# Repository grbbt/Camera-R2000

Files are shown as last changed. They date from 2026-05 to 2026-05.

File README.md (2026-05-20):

# R2000

> A compact, round-bodied digital camera built around the ESP32-P4, designed for fun, accessible photography with a deliberate film-inspired aesthetic.





---

## Overview

The R2000 is a hand-held digital camera on an 70mm circular PCB. Fixed-focus wide-angle lens, film-style filters, RGB flash, and a round touchscreen — all driven by an ESP32-P4 + ESP32-C6 SOM. It's a camera that prioritises feel and fun over clinical image quality.

---

## Features

- **80mm round PCB** — compact, pocketable form factor
- **OV5640 MIPI CSI-2 sensor** — 5MP, fixed focus, wide angle (~1.5m hyperfocal)
- **2.1" round ST7701S touchscreen** — live viewfinder and menu UI via LVGL
- **3-channel RGB flash** — independent R/G/B control for software-adjustable colour temperature
- **Film aesthetic filters** — colour grading, grain, vignette, and light leak applied in-camera
- **microSD card storage** — JPEG capture written directly from hardware encoder
- **USB-C** — charging and file transfer
- **1000mAh LiPo** — onboard single-cell battery

---

## Electrical Hardware

### Core SOM

**Guition JC-ESP32P4-M3-C6** — a dual-chip SOM combining:
- **ESP32-P4** — main application processor, MIPI CSI camera input, RGB display output, hardware JPEG encode, SD/MMC
- **ESP32-C6** — WiFi 6 / BLE 5 radio for wireless transfer and future remote control

### Schematic

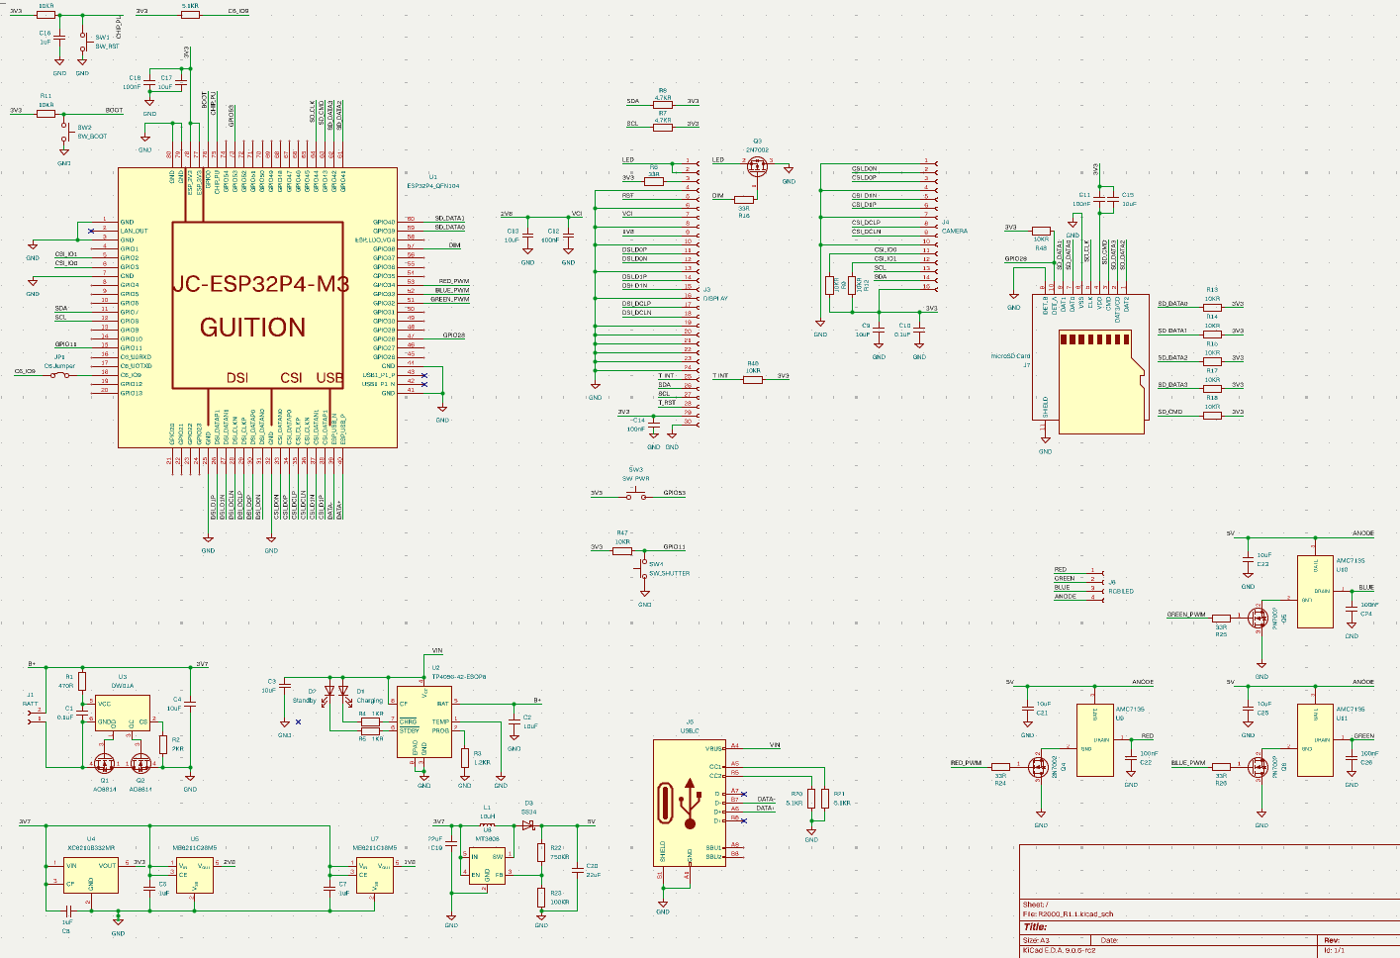
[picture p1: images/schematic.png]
Schematic


### PCB

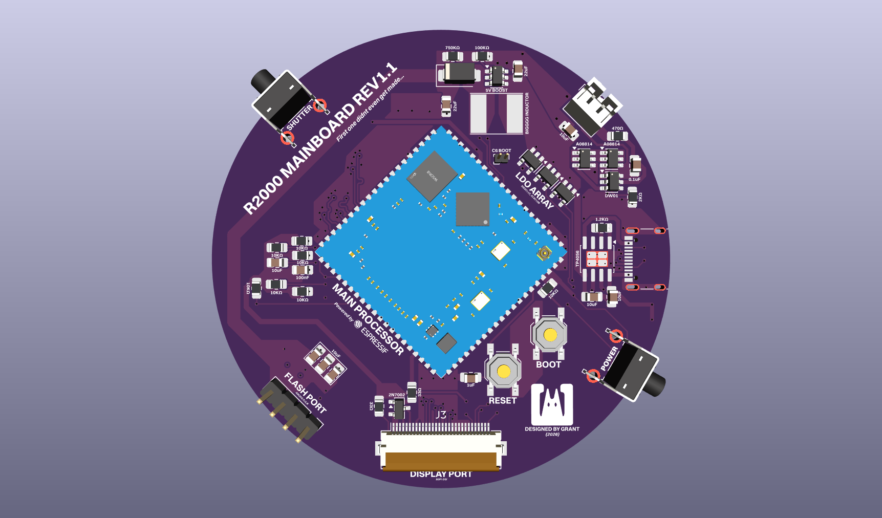
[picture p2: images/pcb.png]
PCB


| Parameter | Value |
|---|---|
| Diameter | 70mm |
| Layers | 4 |
| Design tool | KiCad |

- LDO bank placed adjacent to OV5640 to keep power traces short
- MT3608 boost converter isolated from camera rails to reduce switching noise
- RGB panel interface traces serpentined for length matching
- SD card traces kept short with 10kΩ pull-ups on CMD and DAT lines

### Camera

| Parameter | Value |
|---|---|
| Sensor | OV5640 |
| Interface | MIPI CSI-2 (2-lane) |
| Resolution | 5MP (2592×1944) |
| Focus | Fixed, wide angle |
| Hyperfocal | ~1.5m (everything from ~80cm to ∞ sharp) |
| Autofocus | None — VCM unused |

### Display

| Parameter | Value |
|---|---|
| Driver IC | ST7701S |
| Size | 2.1" round |
| Diameter | ~54mm |
| Interface | RGB parallel |
| Touch IC | GT911 (I2C) |

### Flash

Three independent channels let you tune the colour temperature of each shot in software — or go full auto white-balance assist by sampling the scene before firing.

| Channel | Driver | Supply |
|---|---|---|
| Red 1W LED | AMC7135 (350mA CC) | 5V (MT3608 boost) |
| Green 1W LED | AMC7135 (350mA CC) | 5V (MT3608 boost) |
| Blue 1W LED | AMC7135 (350mA CC) | 5V (MT3608 boost) |

### Power

| Rail | Regulator | Supplies |
|---|---|---|
| 3.3V | XC6210B332 (1A) | SOM, display logic, SD, GT911 |
| 2.8V | ME6211C28 (600mA) | OV5640 AVDD |
| 1.8V | ME6211C18 (600mA) | OV5640 DOVDD |
| 1.5V | ME6211C15 (600mA) | OV5640 DVDD |
| 5V (flash) | MT3608 boost | RGB flash rail |

Battery: 1000mAh single-cell LiPo, ~503040 form factor, charged via TP5100.

---

## Firmware

### Stack

| Layer | Component |
|---|---|
| RTOS | FreeRTOS (via ESP-IDF v5.3+) |
| Camera | `esp_cam_sensor` + `esp_video` (MIPI CSI DMA) |
| JPEG encode | `esp_jpeg` — hardware-accelerated on ESP32-P4 |
| Display | `esp_lcd` (ST7701S) + `esp_lcd_touch` (GT911) |
| UI | LVGL — hardware-accelerated via P4 PPA |
| Storage | `esp_vfs_fat` + `sdmmc` |

### Task Architecture

```
Core 0                         Core 1
├── Camera capture task        ├── LVGL UI task
├── JPEG encode task           └── Touch polling task
└── SD write task
```

Both cores run in genuine parallel — the live viewfinder never stutters during a write.

### Capture Pipeline

```
OV5640 sensor
  └── MIPI CSI-2 DMA → PSRAM framebuffer
        └── HW JPEG encoder
              └── SD write (FAT32)
                    └── JPEG file
```

### Filters

- **Colour grading** — warm/cool/cross-process presets
- **Grain simulation** — luminance-dependent noise overlay
- **Vignette** — radial falloff, adjustable intensity
- **Light leak** — randomised edge flare, optional per-shot

---

## Getting Started

### Prerequisites

- ESP-IDF v5.3 or later ([installation guide](https://docs.espressif.com/projects/esp-idf/en/latest/esp32p4/get-started/))
- KiCad 8.x for hardware files

### Build Firmware

```bash
git clone https://github.com/yourusername/R2000.git
cd R2000/firmware

idf.py set-target esp32p4
idf.py menuconfig     # Set SD card GPIO, display config, etc.
idf.py build
idf.py -p /dev/ttyUSBx flash monitor
```

### Hardware Assembly

1. Order PCB from JLCPCB using files in `hardware/pcb/`
2. Source components from `hardware/bom/` — LCSC preferred for basic parts
3. Flash firmware before installing display and camera to simplify debug access

---

## GPIO Map

See [`docs/gpio_map.md`](docs/gpio_map.md) for the full 30-pin assignment covering RGB display, GT911 touch, OV5640 MIPI/I2C/XCLK, SD card, flash channels, and shutter button.

---

## Design Philosophy

The R2000 isn't trying to be a precise instrument. No AF hunting, no deep menus, no lab-grade colour science. Wide angle and fixed focus means everything is sharp the moment you raise it. The filters are baked in, not bolted on. Round is unusual and that's the point.

If you want clinical accuracy, this is the wrong camera. If you want something that makes you actually want to take pictures, that's what this is for.

---

## Status

| Electrical | Status |
|---|---|
| PCB layout | ✅ First pass complete |
| Power system | ✅ LDO selection finalised |
| PCB Assembly & Testing | 🔧 In progress |

| Software | Status |
|---|---|
| Display / LVGL | 🔧 In progress |
| WiFi upload (C6) | 🔧 In progress |
| RGB flash driver | ⬜ Not started |
| Film filters | ⬜ Not started |
| SD storage | ⬜ Not started |

| Hardware | Status |
|---|---|
| Case Initial Design | 🔧 In progress |
| Case Prototyping | 🔧 In progress |

---

## License

Hardware and firmware released under [MIT License](LICENSE).

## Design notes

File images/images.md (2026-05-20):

# Development images
---
Schematic
PCB

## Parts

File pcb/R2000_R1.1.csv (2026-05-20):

Reference | Qty | Value | DNP | Exclude from BOM | Exclude from Board | Footprint | Datasheet
C1,C10 | 2 | 0.1uF |  |  |  | Capacitor_SMD:C_0805_2012Metric_Pad1.18x1.45mm_HandSolder | ~
C2,C3,C4,C9,C13,C15,C17,C21,C23,C25 | 10 | 10uF |  |  |  | Capacitor_SMD:C_0805_2012Metric_Pad1.18x1.45mm_HandSolder | ~
C5,C7,C8,C16 | 4 | 1uF |  |  |  | Capacitor_SMD:C_0805_2012Metric_Pad1.18x1.45mm_HandSolder | ~
C11,C12,C14,C18,C22,C24,C26 | 7 | 100nF |  |  |  | Capacitor_SMD:C_0805_2012Metric_Pad1.18x1.45mm_HandSolder | ~
C19,C20 | 2 | 22uF |  |  |  | Capacitor_SMD:C_0805_2012Metric_Pad1.18x1.45mm_HandSolder | ~
D1 | 1 | Charging |  |  |  | LED_SMD:LED_1206_3216Metric_Pad1.42x1.75mm_HandSolder | ~
D2 | 1 | Standby |  |  |  | LED_SMD:LED_1206_3216Metric_Pad1.42x1.75mm_HandSolder | ~
D3 | 1 | SS34 |  |  |  | Diode_SMD:D_SMA | https://www.vishay.com/docs/88751/ss32.pdf
J1 | 1 | BATT |  |  |  | Connector_JST:JST_PH_B2B-PH-K_1x02_P2.00mm_Vertical | ~
J3 | 1 | DISPLAY |  |  |  | Connector_FFC-FPC:Hirose_FH12-30S-0.5SH_1x30-1MP_P0.50mm_Horizontal | ~
J4 | 1 | CAMERA |  |  |  | Connector_FFC-FPC:TE_1-84952-5_1x15-1MP_P1.0mm_Horizontal | ~
J5 | 1 | USB_C |  |  |  | Connector_USB:USB_C_Receptacle_G-Switch_GT-USB-7010ASV | https://www.usb.org/sites/default/files/documents/usb_type-c.zip
J6 | 1 | RGB LED |  |  |  | Connector_PinHeader_2.54mm:PinHeader_1x04_P2.54mm_Vertical | ~
J7 | 1 | microSD Card |  |  |  | Connector_Card:microSD_HC_Hirose_DM3AT-SF-PEJM5 | https://www.hirose.com/en/product/document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
JP1 | 1 | C6 Jumper |  |  |  | Connector_PinHeader_1.00mm:PinHeader_1x02_P1.00mm_Vertical | ~
L1 | 1 | 10uH |  |  |  | Inductor_SMD:L_Taiyo-Yuden_NR-60xx_HandSoldering | ~
Q1,Q2 | 2 | AO8814 |  |  |  | Package_TO_SOT_SMD:TSOT-23-6 | https://fscdn.rohm.com/en/products/databook/datasheet/discrete/transistor/mosfet/rq6e080ajtcr-e.pdf
Q3,Q4,Q5,Q6 | 4 | 2N7002 |  |  |  | Package_TO_SOT_SMD:SOT-23 | https://www.onsemi.com/pub/Collateral/NDS7002A-D.PDF
R1 | 1 | 470R |  |  |  | Resistor_SMD:R_0805_2012Metric_Pad1.20x1.40mm_HandSolder | ~
R2 | 1 | 2KR |  |  |  | Resistor_SMD:R_0805_2012Metric_Pad1.20x1.40mm_HandSolder | ~
R3 | 1 | 1.2KR |  |  |  | Resistor_SMD:R_0805_2012Metric_Pad1.20x1.40mm_HandSolder | ~
R4,R5 | 2 | 1KR |  |  |  | Resistor_SMD:R_0805_2012Metric_Pad1.20x1.40mm_HandSolder | ~
R6,R16,R24,R25,R26 | 5 | 33R |  |  |  | Resistor_SMD:R_0805_2012Metric_Pad1.20x1.40mm_HandSolder | ~
R7,R8 | 2 | 4.7KR |  |  |  | Resistor_SMD:R_0805_2012Metric_Pad1.20x1.40mm_HandSolder | ~
R9,R10,R11,R12,R13,R14,R15,R17,R18,R46,R47,R48 | 12 | 10KR |  |  |  | Resistor_SMD:R_0805_2012Metric_Pad1.20x1.40mm_HandSolder | ~
R19,R20,R21 | 3 | 5.1KR |  |  |  | Resistor_SMD:R_0805_2012Metric_Pad1.20x1.40mm_HandSolder | ~
R22 | 1 | 750KR |  |  |  | Resistor_SMD:R_0805_2012Metric_Pad1.20x1.40mm_HandSolder | ~
R23 | 1 | 100KR |  |  |  | Resistor_SMD:R_0805_2012Metric_Pad1.20x1.40mm_HandSolder | ~
SW1 | 1 | SW_RST |  |  |  | Button_Switch_SMD:SW_SPST_TL3342 | ~
SW2 | 1 | SW_BOOT |  |  |  | Button_Switch_SMD:SW_SPST_TL3342 | ~
SW3 | 1 | SW_PWR |  |  |  | Button_Switch_THT:SW_Tactile_SPST_Angled_PTS645Vx58-2LFS | ~
SW4 | 1 | SW_SHUTTER |  |  |  | Button_Switch_THT:SW_Tactile_SPST_Angled_PTS645Vx58-2LFS | ~
U1 | 1 | ESP32P4_QFN104 |  |  |  | Guition ESP32:JC-ESP32P4-M3_V0.2
U2 | 1 | TP4056-42-ESOP8 |  |  |  | Package_SO:SOIC-8-1EP_3.9x4.9mm_P1.27mm_EP2.41x3.3mm_ThermalVias | https://www.lcsc.com/datasheet/lcsc_datasheet_2410121619_TOPPOWER-Nanjing-Extension-Microelectronics-TP4056-42-ESOP8_C16581.pdf
U3 | 1 | DW01A |  |  |  | Package_TO_SOT_SMD:SOT-23-6 | https://hmsemi.com/downfile/DW01A.PDF
U4 | 1 | XC6210B332MR |  |  |  | Package_TO_SOT_SMD:SOT-23-5 | https://www.torexsemi.com/file/xc6210/XC6210.pdf
U5 | 1 | ME6211C28M5 |  |  |  | Package_TO_SOT_SMD:SOT-23-5 | https://www.lcsc.com/datasheet/lcsc_datasheet_2304140030_MICRONE-Nanjing-Micro-One-Elec-ME6211C33R5G_C235316.pdf
U7 | 1 | ME6211C18M5 |  |  |  | Package_TO_SOT_SMD:SOT-23-5 | https://www.lcsc.com/datasheet/lcsc_datasheet_2304140030_MICRONE-Nanjing-Micro-One-Elec-ME6211C33R5G_C235316.pdf
U8 | 1 | MT3608 |  |  |  | Package_TO_SOT_SMD:SOT-23-6 | https://www.olimex.com/Products/Breadboarding/BB-PWR-3608/resources/MT3608.pdf
U9,U10,U11 | 3 | AMC7135 |  |  |  | AMC7135:AMC7135_ASAP

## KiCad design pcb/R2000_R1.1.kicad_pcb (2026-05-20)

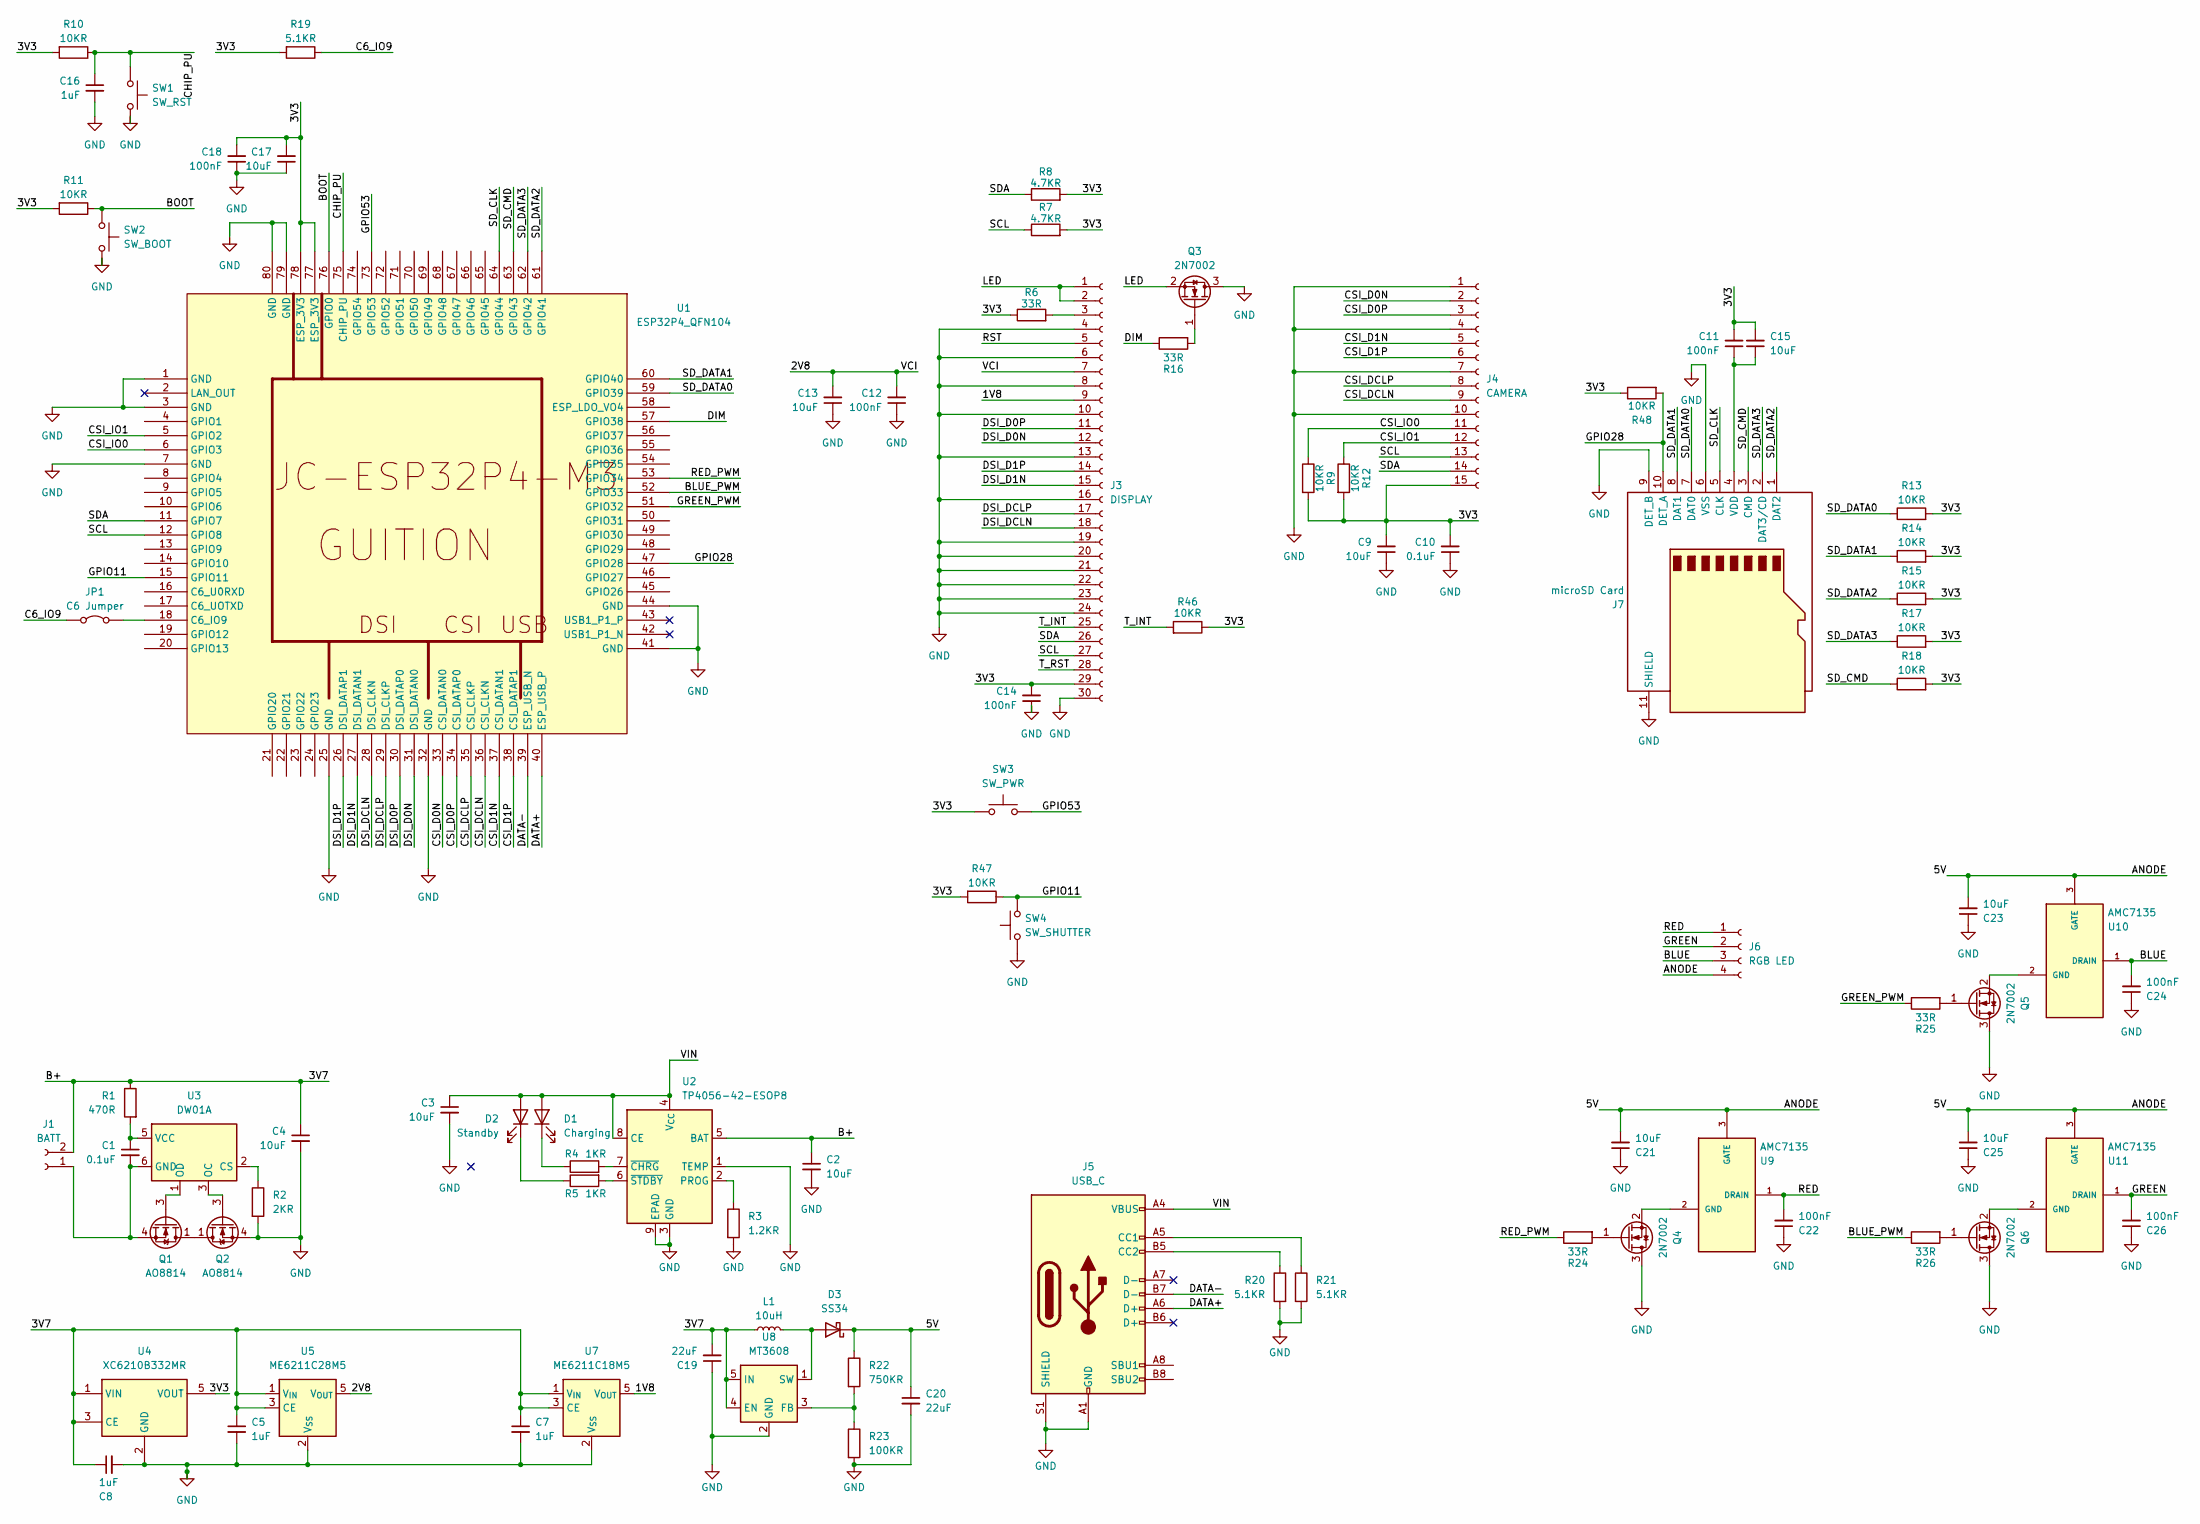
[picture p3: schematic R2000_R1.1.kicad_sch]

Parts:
C1, C10: 0.1uF; C_0805_2012Metric_Pad1.18x1.45mm_HandSolder
C2, C3, C4, C9, C13, C15, C17, C21, C23, C25: 10uF; C_0805_2012Metric_Pad1.18x1.45mm_HandSolder
C5, C7, C8, C16: 1uF; C_0805_2012Metric_Pad1.18x1.45mm_HandSolder
C11, C12, C14, C18, C22, C24, C26: 100nF; C_0805_2012Metric_Pad1.18x1.45mm_HandSolder
C19, C20: 22uF; C_0805_2012Metric_Pad1.18x1.45mm_HandSolder
D1: Charging; LED_1206_3216Metric_Pad1.42x1.75mm_HandSolder
D2: Standby; LED_1206_3216Metric_Pad1.42x1.75mm_HandSolder
D3: SS34; D_SMA
J1: BATT; JST_PH_B2B-PH-K_1x02_P2.00mm_Vertical
J3: DISPLAY; Hirose_FH12-30S-0.5SH_1x30-1MP_P0.50mm_Horizontal
J4: CAMERA; TE_1-84952-5_1x15-1MP_P1.0mm_Horizontal
J5: USB_C; USB_C_Receptacle_G-Switch_GT-USB-7010ASV
J6: RGB LED; PinHeader_1x04_P2.54mm_Vertical
J7: microSD Card; microSD_HC_Hirose_DM3AT-SF-PEJM5
JP1: C6 Jumper; PinHeader_1x02_P1.00mm_Vertical
L1: 10uH; L_Taiyo-Yuden_NR-60xx_HandSoldering
Q1, Q2: AO8814; TSOT-23-6
Q3, Q4, Q5, Q6: 2N7002; SOT-23
R1: 470R; R_0805_2012Metric_Pad1.20x1.40mm_HandSolder
R2: 2KR; R_0805_2012Metric_Pad1.20x1.40mm_HandSolder
R3: 1.2KR; R_0805_2012Metric_Pad1.20x1.40mm_HandSolder
R4, R5: 1KR; R_0805_2012Metric_Pad1.20x1.40mm_HandSolder
R6, R16, R24, R25, R26: 33R; R_0805_2012Metric_Pad1.20x1.40mm_HandSolder
R7, R8: 4.7KR; R_0805_2012Metric_Pad1.20x1.40mm_HandSolder
R9, R10, R11, R12, R13, R14, R15, R17, R18, R46, R47, R48: 10KR; R_0805_2012Metric_Pad1.20x1.40mm_HandSolder
R19, R20, R21: 5.1KR; R_0805_2012Metric_Pad1.20x1.40mm_HandSolder
R22: 750KR; R_0805_2012Metric_Pad1.20x1.40mm_HandSolder
R23: 100KR; R_0805_2012Metric_Pad1.20x1.40mm_HandSolder
SW1: SW_RST; SW_SPST_TL3342
SW2: SW_BOOT; SW_SPST_TL3342
SW3: SW_PWR; SW_Tactile_SPST_Angled_PTS645Vx58-2LFS
SW4: SW_SHUTTER; SW_Tactile_SPST_Angled_PTS645Vx58-2LFS
U1: ESP32P4_QFN104; JC-ESP32P4-M3_V0.2
U2: TP4056-42-ESOP8; SOIC-8-1EP_3.9x4.9mm_P1.27mm_EP2.41x3.3mm_ThermalVias
U3: DW01A; SOT-23-6
U4: XC6210B332MR; SOT-23-5
U5: ME6211C28M5; SOT-23-5
U7: ME6211C18M5; SOT-23-5
U8: MT3608; SOT-23-6
U9, U10, U11: AMC7135; AMC7135_ASAP

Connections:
/1V8: J3.9, U7.5 (V_{OUT})
/2V8: C12.2, C13.2, J3.7, U5.5 (V_{OUT})
/3V3: C9.2, C10.2, C11.2, C14.2, C15.2, C17.2, C18.2, J3.29, J4.15, R6.1, R7.2, R8.2, R9.2, R10.2, R11.2, R12.2, R13.2, R14.2, R15.2, R17.2, R18.2, R19.2, R46.1, R47.2, R48.1, SW3.1, U1.77 (ESP_3V3), U1.78 (ESP_3V3), U4.5 (VOUT); also elsewhere on the board
/3V7: C2.1, C4.1, C5.1, C7.1, C8.1, C19.2, J1.2, L1.1, R1.1, U2.5 (BAT), U4.1 (VIN), U4.3 (CE), U5.1 (V_{IN}), U5.3 (CE), U7.1 (V_{IN}), U7.3 (CE), U8.4 (EN), U8.5 (IN); also elsewhere on the board
/5V: C20.1, C21.2, C23.2, C25.2, D3.1 (K), J6.4, R22.1, U9.3 (GATE), U10.3 (GATE), U11.3 (GATE)
/BLUE: C24.2, J6.3, U10.1 (DRAIN)
/BLUE_PWM: R26.1, U1.52 (GPIO33)
/BOOT: R11.1, SW2.1, U1.76 (GPIO0)
/C6_IO9: JP1.1 (A), R19.1
/CHIP_PU: C16.1, R10.1, SW1.1, U1.75 (CHIP_PU)
/CSI_D0N: J4.2, U1.33 (CSI_DATAN0)
/CSI_D0P: J4.3, U1.34 (CSI_DATAP0)
/CSI_D1N: J4.5, U1.37 (CSI_DATAN1)
/CSI_D1P: J4.6, U1.38 (CSI_DATAP1)
/CSI_DCLN: J4.9, U1.36 (CSI_CLKN)
/CSI_DCLP: J4.8, U1.35 (CSI_CLKP)
/CSI_IO0: J4.11, R9.1, U1.6 (GPIO3)
/CSI_IO1: J4.12, R12.1, U1.5 (GPIO2)
/DATA+: J5.A6 (D+), U1.40 (ESP_USB_P)
/DATA-: J5.B7 (D-), U1.39 (ESP_USB_N)
/DIM: R16.1, U1.57 (GPIO38)
/DSI_D0N: J3.12, U1.31 (DSI_DATAN0)
/DSI_D0P: J3.11, U1.30 (DSI_DATAP0)
/DSI_D1N: J3.15, U1.27 (DSI_DATAN1)
/DSI_D1P: J3.14, U1.26 (DSI_DATAP1)
/DSI_DCLN: J3.18, U1.28 (DSI_CLKN)
/DSI_DCLP: J3.17, U1.29 (DSI_CLKP)
/GPIO11: R47.1, SW4.2, U1.15 (GPIO11); also elsewhere on the board
/GPIO28: J7.10 (DET_A), R48.2, U1.47 (GPIO28)
/GPIO53: SW3.2, U1.73 (GPIO53); also elsewhere on the board
/GREEN: C26.2, J6.2, U11.1 (DRAIN)
/GREEN_PWM: R25.1, U1.51 (GPIO32)
/LED: J3.1, J3.2, Q3.2 (S)
/RED: C22.2, J6.1, U9.1 (DRAIN)
/RED_PWM: R24.1, U1.53 (GPIO34)
/RST: J3.5
/SCL: J3.27, J4.13, R7.1, U1.12 (GPIO8)
/SDA: J3.26, J4.14, R8.1, U1.11 (GPIO7)
/SD_CLK: J7.5 (CLK), U1.64 (GPIO44)
/SD_CMD: J7.3 (CMD), R18.1, U1.63 (GPIO43)
/SD_DATA0: J7.7 (DAT0), R13.1, U1.59 (GPIO39)
/SD_DATA1: J7.8 (DAT1), R14.1, U1.60 (GPIO40)
/SD_DATA2: J7.1 (DAT2), R15.1, U1.61 (GPIO41)
/SD_DATA3: J7.2 (DAT3/CD), R17.1, U1.62 (GPIO42)
/T_INT: J3.25, R46.2
/T_RST: J3.28
/VIN: C3.1, D1.2 (A), D2.2 (A), J5.A4 (VBUS), J5.A9 (VBUS), J5.B4 (VBUS), J5.B9 (VBUS), U2.4 (V_{CC}), U2.8 (CE)
GND: C2.2, C3.2, C4.2, C5.2, C7.2, C8.2, C9.1, C10.1, C12.1, C13.1, C14.1, C16.2, C17.1, C18.1, C19.1, C20.2, C21.1, C22.1, C23.1, C24.1, C25.1, C26.1, J3.4, J3.6, J3.8, J3.10, J3.13, J3.16, J3.19, J3.20, J3.21, J3.22, J3.23, J3.24, J3.30, J4.1, J4.4, J4.7, J4.10, J5.A1 (GND), J5.A12 (GND), J5.B1 (GND), J5.B12 (GND), J5.S1 (SHIELD), J7.6 (VSS), J7.9 (DET_B), J7.11 (SHIELD), Q2.4 (S), Q3.3 (D), Q4.3 (D), Q5.3 (D), Q6.3 (D), R2.2, R3.2, R20.2, R21.2, R23.2, SW1.2, SW2.2, SW4.1, U1.1 (GND), U1.3 (GND), U1.7 (GND), U1.25 (GND), U1.32 (GND), U1.41 (GND), U1.44 (GND), U1.79 (GND), U1.80 (GND), U2.1 (TEMP), U2.3 (GND), U2.9 (EPAD), U4.2 (GND), U5.2 (V_{SS}), U7.2 (V_{SS}), U8.2 (GND); also elsewhere on the board
unnamed: D1.1 (K), R4.1
unnamed: D2.1 (K), R5.1
unnamed 50: D3.2 (A), L1.2, U8.1 (SW); also elsewhere on the board
unnamed: C1.2, J1.1, Q1.4 (S), U3.6 (GND)
unnamed: J3.3, R6.2
unnamed: J5.A5 (CC1), R21.1
unnamed: J5.B5 (CC2), R20.1
unnamed: C11.1, C15.1, J7.4 (VDD)
unnamed: JP1.2 (B), U1.18 (C6_IO9)
unnamed: Q1.1 (D), Q1.2 (D), Q1.5 (D), Q1.6 (D), Q2.1 (D), Q2.2 (D), Q2.5 (D), Q2.6 (D)
unnamed: Q1.3 (G), U3.1 (OD)
unnamed: Q2.3 (G), U3.3 (OC)
unnamed: Q3.1 (G), R16.2
unnamed: Q4.1 (G), R24.2
unnamed: Q4.2 (S), U9.2 (GND), U9.2@1 (GND)
unnamed: Q5.1 (G), R25.2
unnamed: Q5.2 (S), U10.2 (GND), U10.2@1 (GND)
unnamed: Q6.1 (G), R26.2
unnamed: Q6.2 (S), U11.2 (GND), U11.2@1 (GND)
unnamed: R3.1, U2.2 (PROG)
unnamed: R4.2, U2.7 (~CHRG)
unnamed: R5.2, U2.6 (~STDBY)
unnamed: R2.1, U3.2 (CS)
unnamed: C1.1, R1.2, U3.5 (VCC)
unnamed 72: R22.2, R23.1, U8.3 (FB); also elsewhere on the board

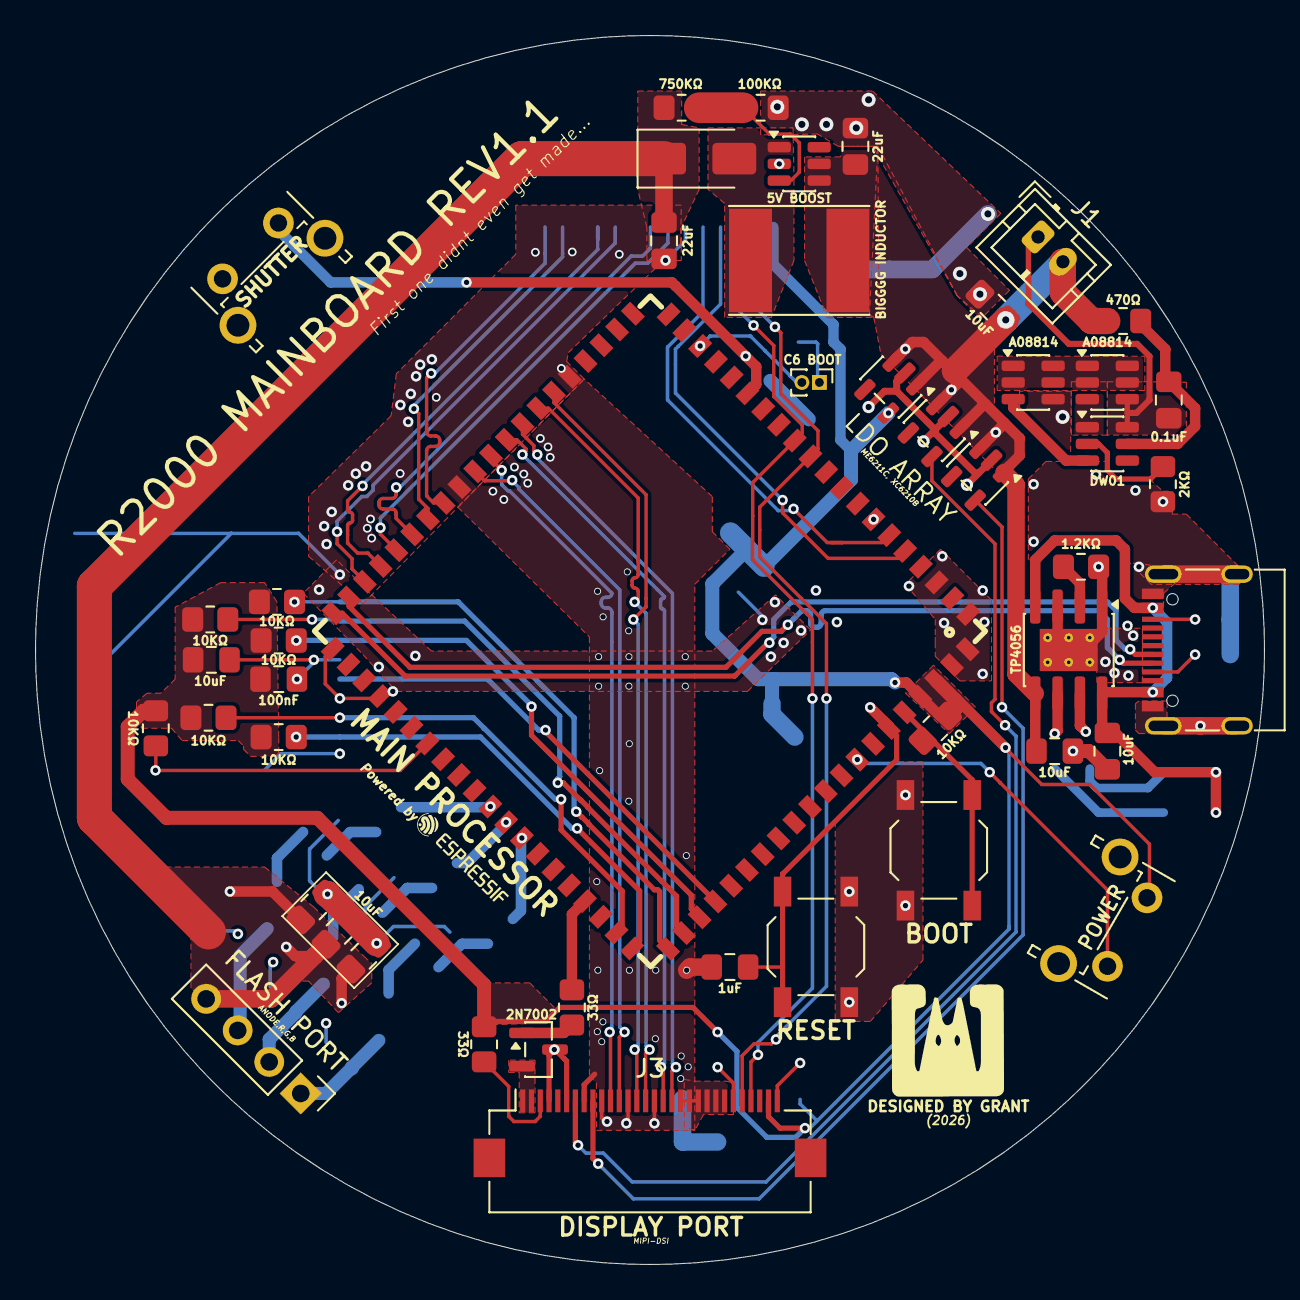
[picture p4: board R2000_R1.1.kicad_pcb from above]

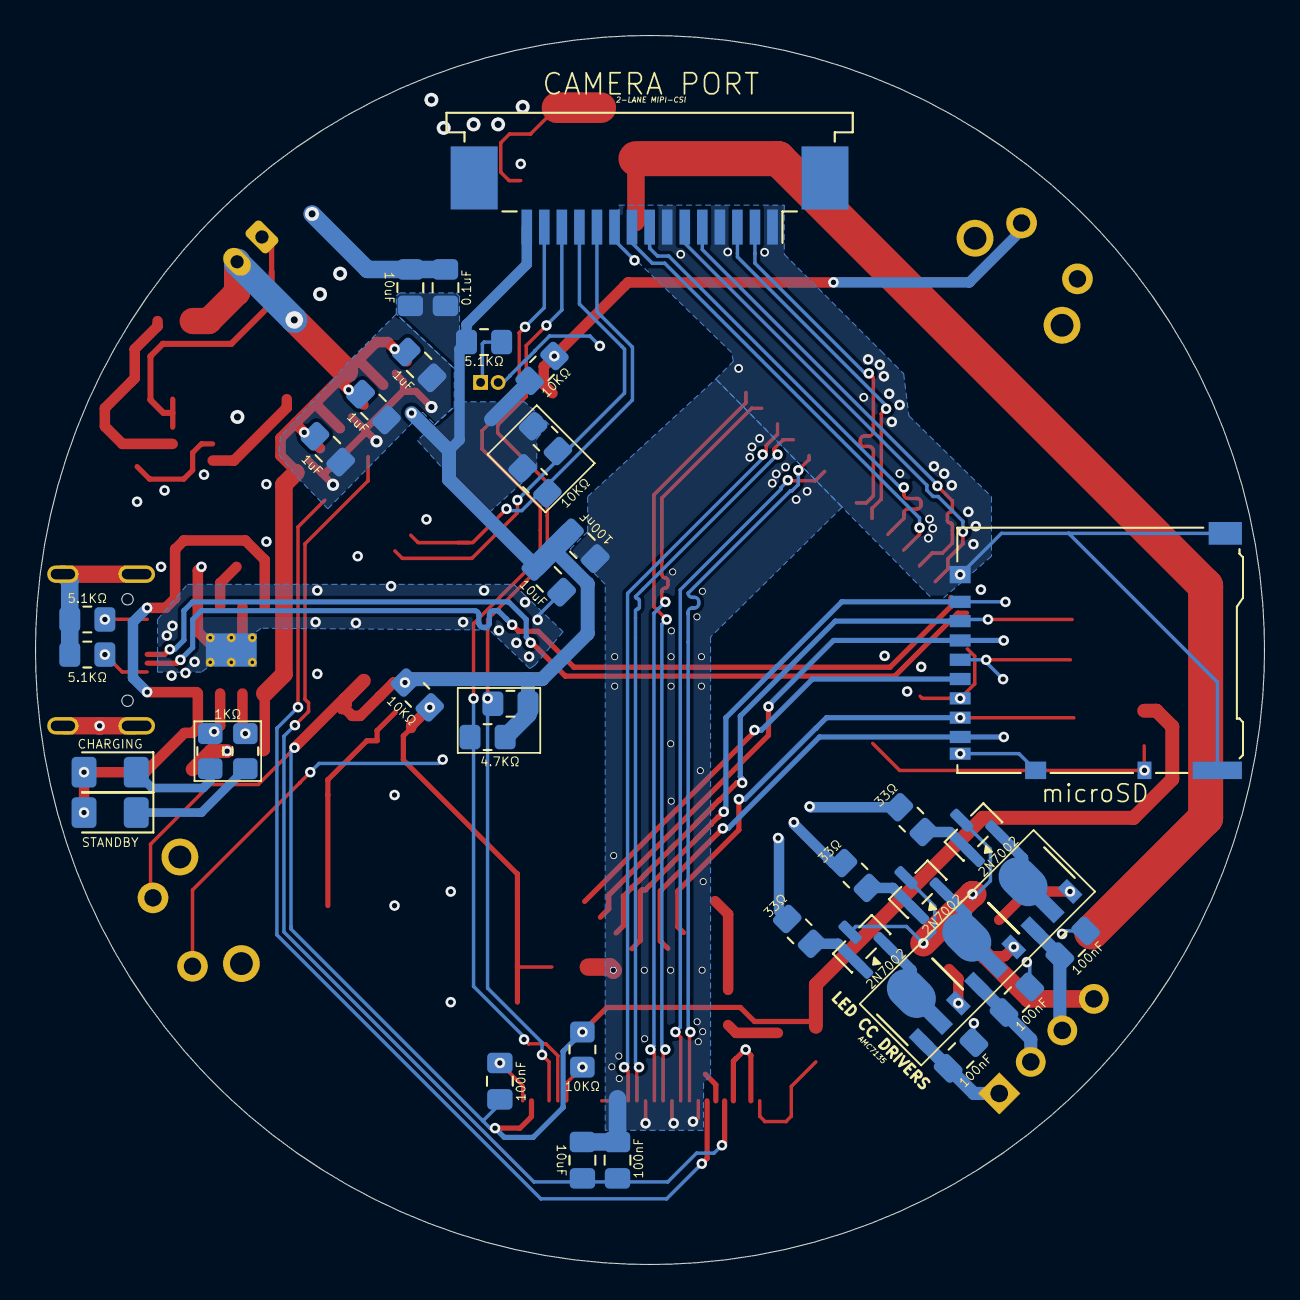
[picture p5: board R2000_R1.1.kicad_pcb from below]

Board: 4 copper layers, 70.0 x 70.0 mm, 85 parts (38 on the bottom side), 71 nets.

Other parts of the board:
5V BOOST: MT3608; SOT-23-6
BIGGGG INDUCTOR: 10uH; L_Taiyo-Yuden_NR-60xx_HandSoldering
POWER: SW_PWR; SW_Tactile_SPST_Angled_PTS645Vx58-2LFS
SHUTTER: SW_SHUTTER; SW_Tactile_SPST_Angled_PTS645Vx58-2LFS

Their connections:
/3V3: POWER.1; also elsewhere on the board
/3V7: 5V BOOST.4 (EN), 5V BOOST.5 (IN), BIGGGG INDUCTOR.1; also elsewhere on the board
/GPIO11: SHUTTER.2; also elsewhere on the board
/GPIO53: POWER.2; also elsewhere on the board
GND: 5V BOOST.2 (GND), SHUTTER.1; also elsewhere on the board
unnamed 50: 5V BOOST.1 (SW), BIGGGG INDUCTOR.2; also elsewhere on the board
unnamed 72: 5V BOOST.3 (FB); also elsewhere on the board
